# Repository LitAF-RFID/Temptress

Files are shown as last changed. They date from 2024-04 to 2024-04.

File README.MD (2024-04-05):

# LitAF Temptress
This device is a miniaturised NFC tag that enables the reading of temperature from two TMP112 sensors as well as a LED that can be enabled or disabled. The NFC interface is provided by an NTAG5 NFC to I2C bridge chip.
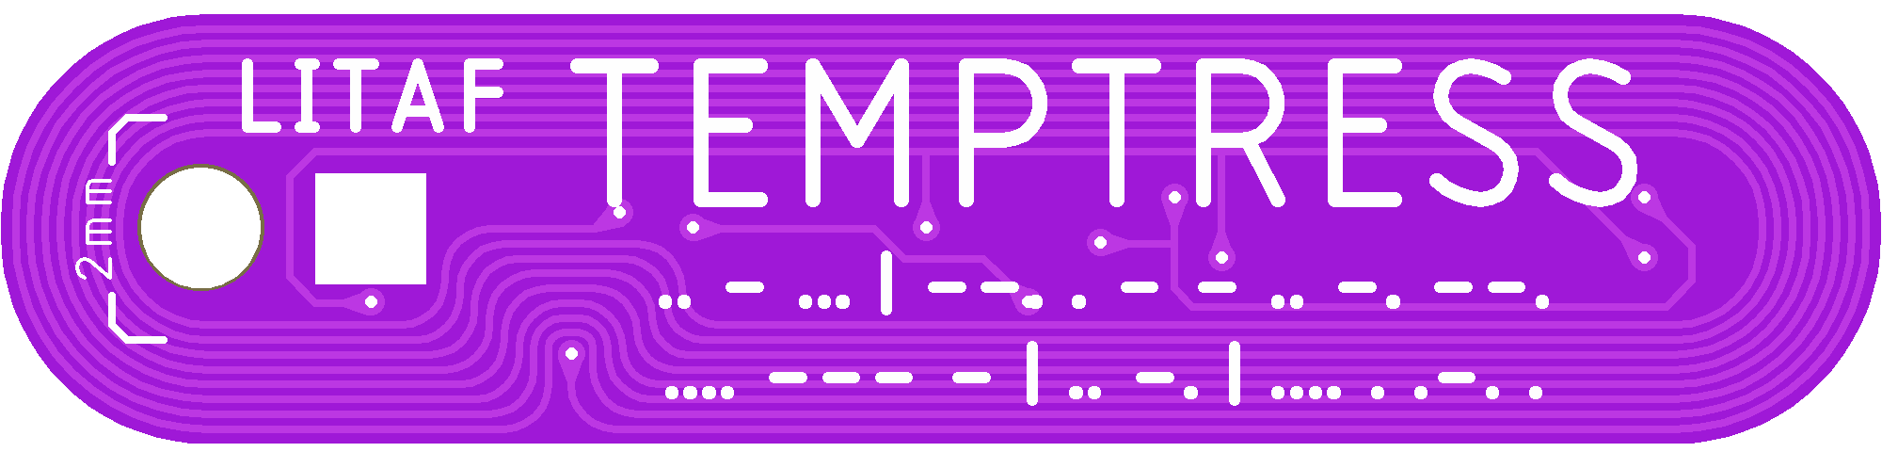
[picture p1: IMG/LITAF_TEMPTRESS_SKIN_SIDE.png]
Top Side PCB Render

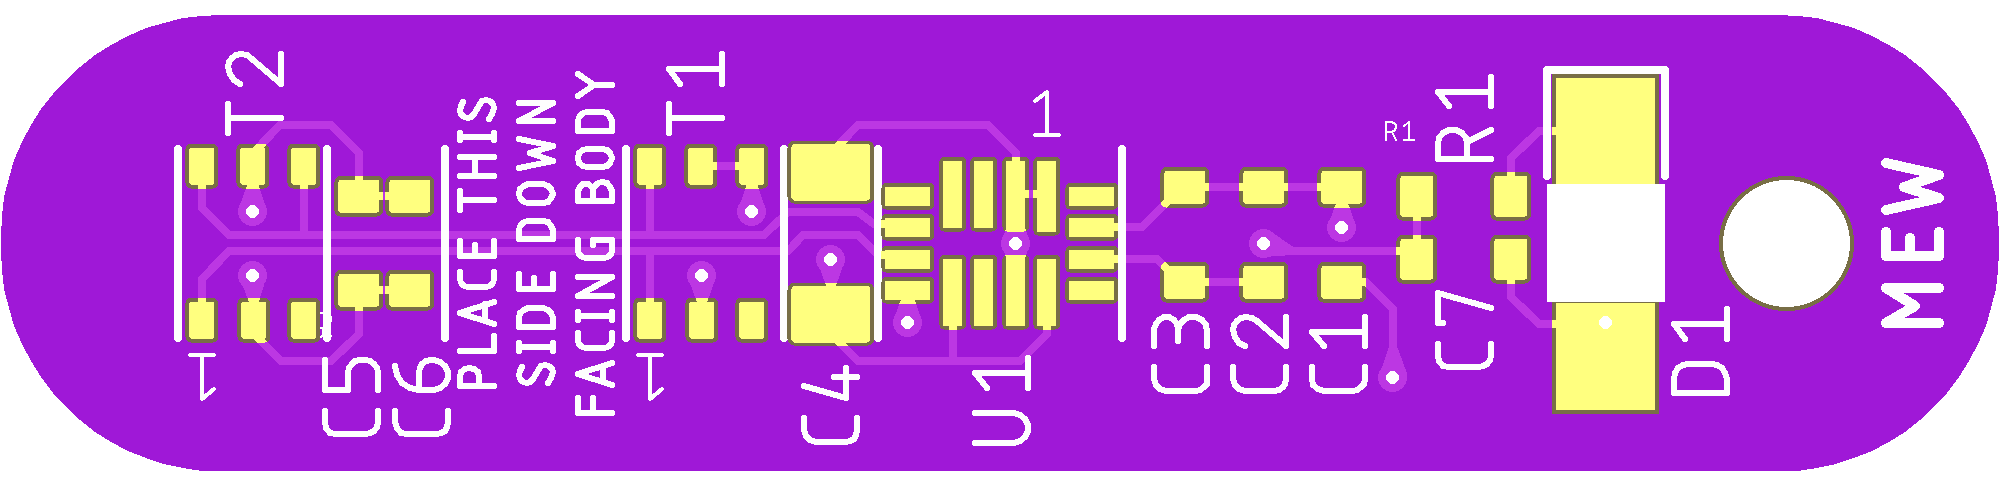
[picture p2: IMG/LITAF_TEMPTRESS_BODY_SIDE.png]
Bot Side PCB Render


## Coil Design
-   **Target Frequency:** 13.56MHz
-   **Target Q Factor:** 50
-   **Chip Capacitance:** 15pf
-   **External Capacitance:** ~62pf
-   **Target Coil Inductance:** 1.76uH
-   **Coil Shape:** "Rectangular"
-   **Coil Height:** 25mm
-   **Coil Width:** 5mm
-   **Coil Turns:** 8
-   **Coil Trace Width:** 0.1mm
-   **Coil Trace Spacing:** 0.1mm
-   **Coil Copper Thickness:** 2oz

## Bill Of Materials
-   1 x NTAG5 (Link or Boost)
-   2 x TMP117
-   3 x Tuning Cap (C1-3)
-   3 x Smoothing Cap (C4-C6)
-   1 x Current Limiting Resistor
-   1 x IN-S124AR LED

## Schematic
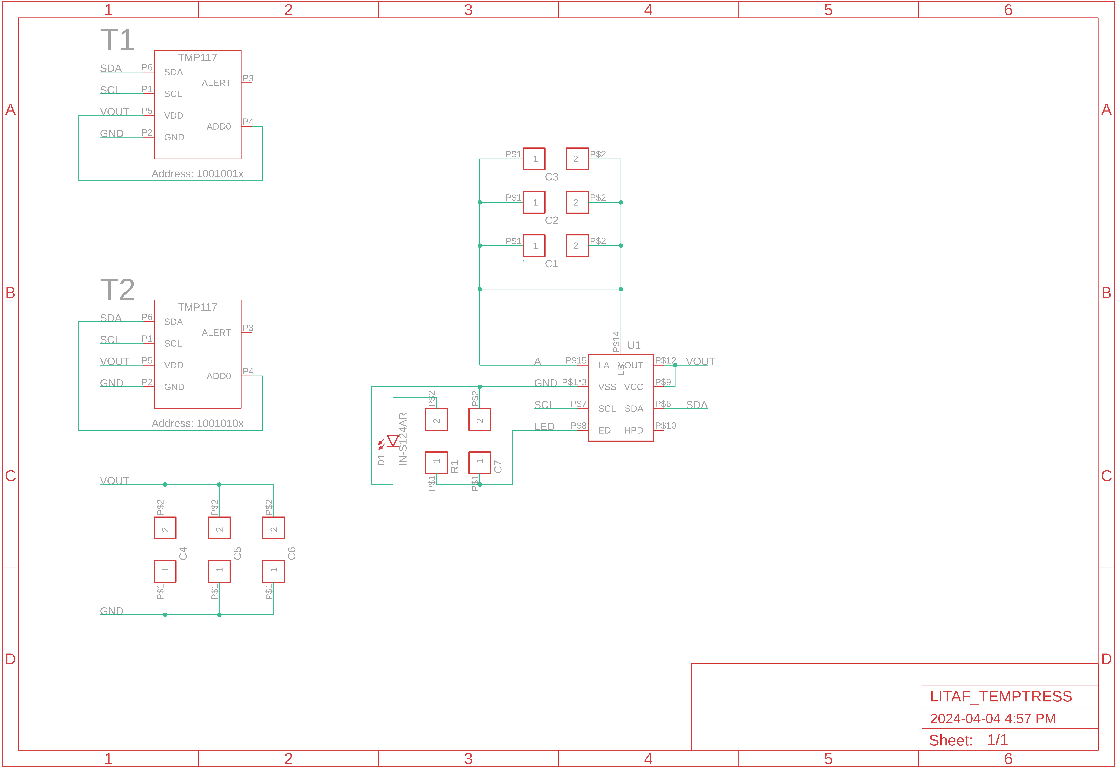
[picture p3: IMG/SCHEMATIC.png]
Schematic


## Note
This was designed as a demo project for a class that I ran. The design has not been tested and was made in a very short period of time. Whilst it should work, it is far from the ideal design for this sort of device.

## Manufacturing Info
This design was created with the PCBWay 2 layer flex PCB manufacturing specifications in mind. If you order this using the CAM files provided, you need to order with 2oz copper.

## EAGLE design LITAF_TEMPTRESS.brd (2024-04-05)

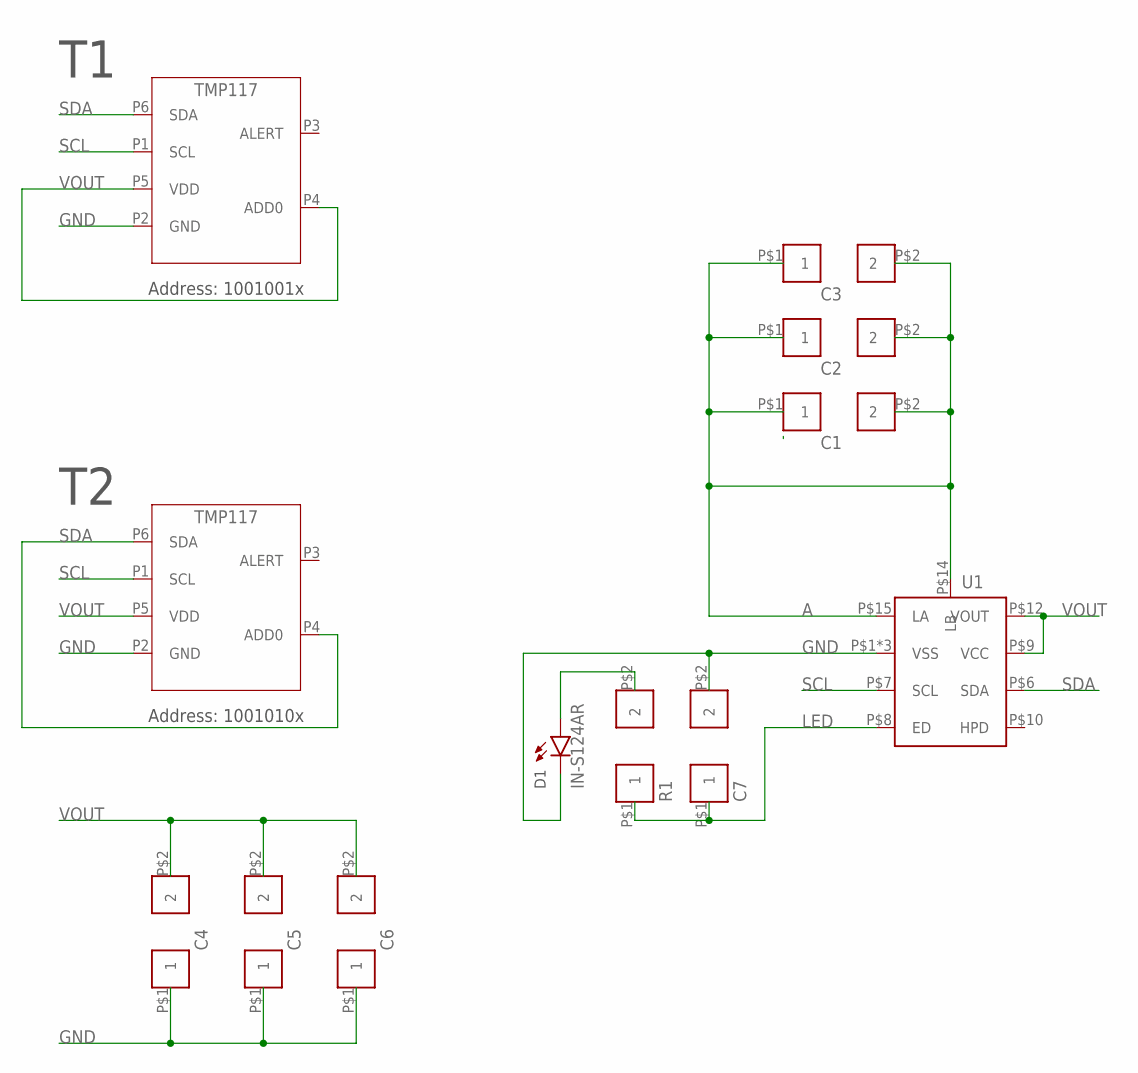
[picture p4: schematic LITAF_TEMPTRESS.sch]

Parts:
C1, C2, C3, C5, C6, C7: 0402-CAP; 0402-SMT
C4: 0603-CAP; 0603-SMT[WIDE]
D1: IN-S124AR
R1: 0402-CAP; 0402-SMT
T1, T2: TMP117; DRV0006B
U1: NTAG5_LINK_NTP53X2; SOT1161-2

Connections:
A: C1.P$1 (1), C1.P$2 (2), C2.P$1 (1), C2.P$2 (2), C3.P$1 (1), C3.P$2 (2), U1.P$14 (LB), U1.P$15 (LA)
GND: C4.P$1 (1), C5.P$1 (1), C6.P$1 (1), C7.P$2 (2), D1.P$2 (C), T1.P2 (GND), T2.P2 (GND), U1.P$1 (VSS), U1.P$2 (VSS), U1.P$11 (VSS)
LED: C7.P$1 (1), R1.P$1 (1), U1.P$8 (ED)
unnamed: D1.P$1 (A), R1.P$2 (2)
SCL: T1.P1 (SCL), T2.P1 (SCL), U1.P$7 (SCL)
SDA: T1.P6 (SDA), T2.P4 (ADD0), T2.P6 (SDA), U1.P$6 (SDA)
VOUT: C4.P$2 (2), C5.P$2 (2), C6.P$2 (2), T1.P4 (ADD0), T1.P5 (VDD), T2.P5 (VDD), U1.P$9 (VCC), U1.P$12 (VOUT)

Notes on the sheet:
Address: 1001001x
Address: 1001010x

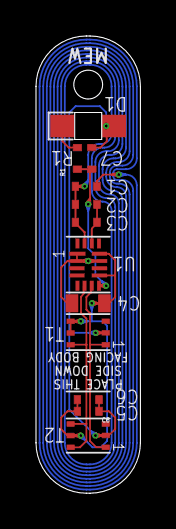
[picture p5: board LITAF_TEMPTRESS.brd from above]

Board: 2 copper layers, 5.8 x 25.4 mm, 12 parts (0 on the bottom side), 7 nets.

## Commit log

2024-04-04 Initial Design
    This has not been peer reviewed or tested, this is just the initial prototype design
    [LITAF_TEMPTRESS.brd, LITAF_TEMPTRESS.sch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]
2024-04-05 Added current limiting resistor for LED
    [LITAF_TEMPTRESS.brd, LITAF_TEMPTRESS.sch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]
